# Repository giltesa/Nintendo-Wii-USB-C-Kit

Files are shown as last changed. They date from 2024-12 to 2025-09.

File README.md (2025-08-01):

# Nintendo Wii / Wii Mini / Wii U: USB-C Kit

The **Nintendo Wii: USB-C Kit** is a board that allows to replace the original power connector for a modern and standard USB-C.

**If your original connector / power supply is too old or damaged** and you need a new one, or **if you would like to power up your Nintendo Wii with a standard USB-C PD charger**, such as the charger for your phone, or laptop, you can do so with this kit.

This board is compatible with these three models:

*   Nintendo Wii
*   Nintendo Wii Mini
*   Nintendo Wii U

## HOW DOES IT WORK?

The **USB-C Power Delivery technology** (**USB-C PD**) allows for communication between the device and the power supply(charger), enabling the negotiation of the voltage to be supplied through the USB-C cable. In this case, the microchip included on this board is configured to request 12v or 15v(1), signaling to the charger that it requires 12v or 15v(1) to run on. If the charger is compatible, it will supply the requested voltage. If it’s not compatible, nothing will happen, and the Nintendo Wii won’t power on.

 **(1)** The circuit has a selection jumper; if you solder it in one position, the circuit will require 12v, and if you solder it in the other position, it will require 15v from the power supply.

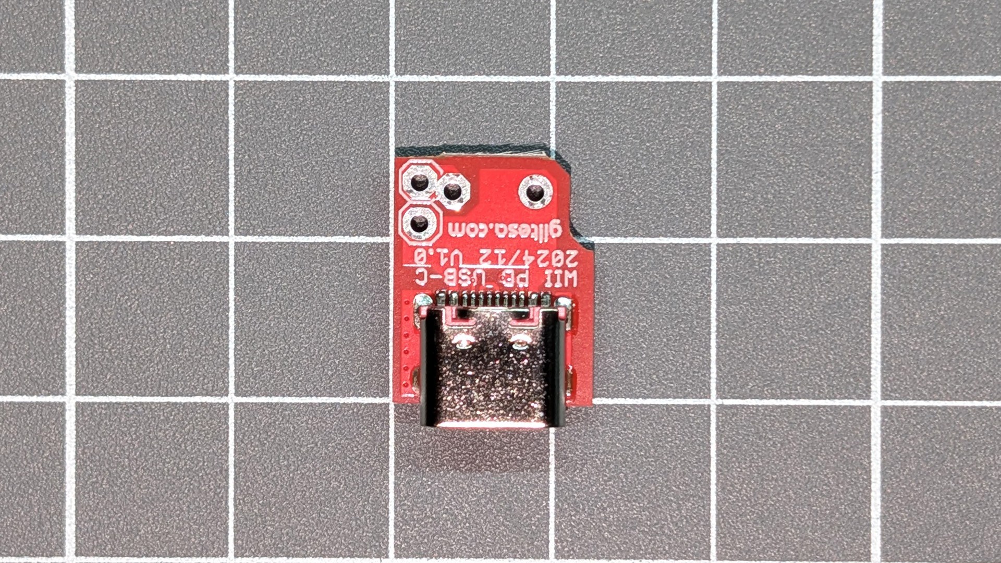
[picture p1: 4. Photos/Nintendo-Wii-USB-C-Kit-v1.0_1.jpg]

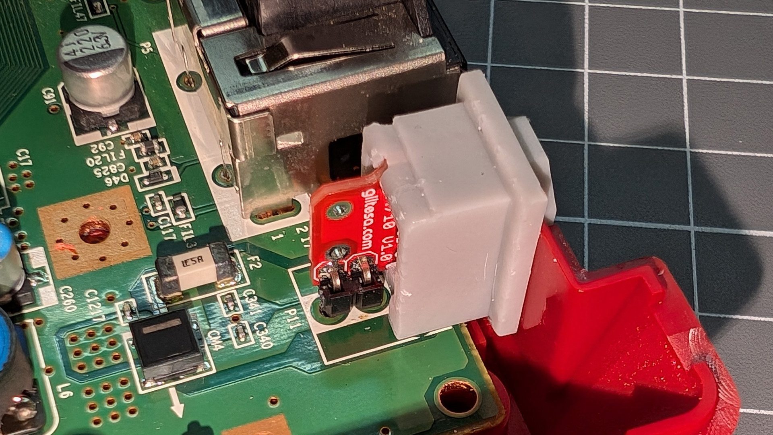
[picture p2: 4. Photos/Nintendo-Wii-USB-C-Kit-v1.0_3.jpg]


## Would you like it?

[**Nintendo Wii: USB-C Kit**](https://shop.giltesa.com/?p=2794)

## License

This project is licensed under a **Creative Commons** license:
**[Attribution-NonCommercial-ShareAlike 4.0 International (CC BY-NC-SA 4.0) ](https://creativecommons.org/licenses/by-nc-sa/4.0/)**

Check the [LICENSE.md](LICENSE.md) for more information.

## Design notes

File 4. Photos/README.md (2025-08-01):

WII
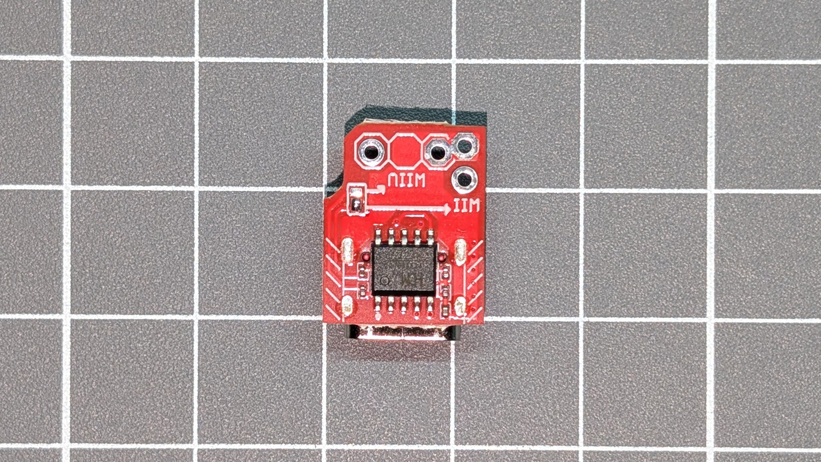
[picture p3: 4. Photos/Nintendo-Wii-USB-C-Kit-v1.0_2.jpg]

WII
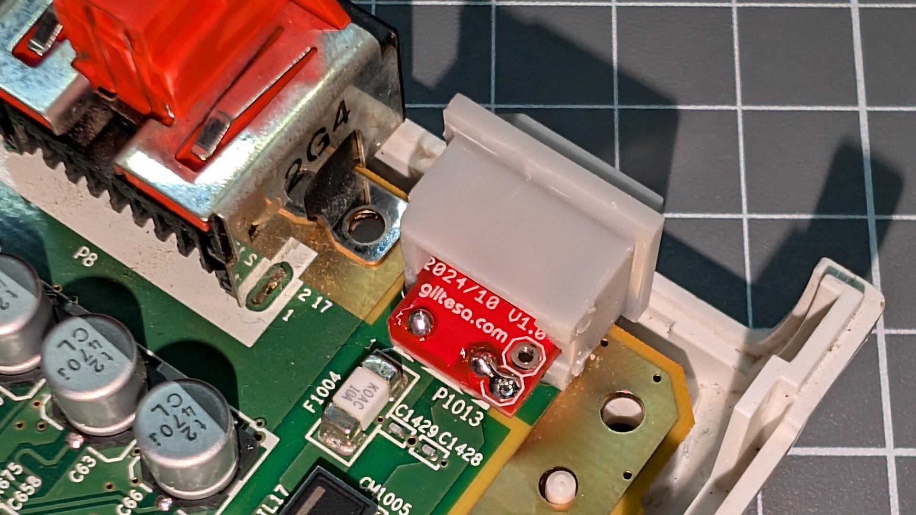
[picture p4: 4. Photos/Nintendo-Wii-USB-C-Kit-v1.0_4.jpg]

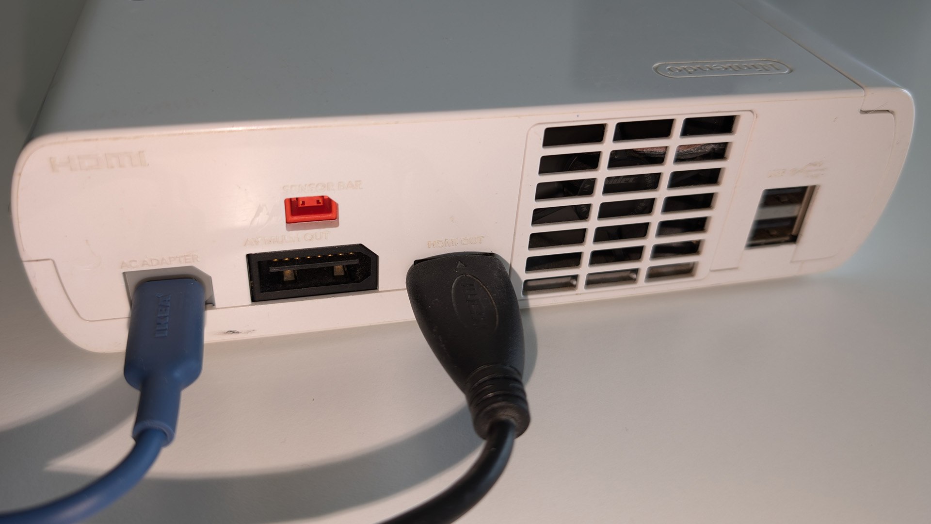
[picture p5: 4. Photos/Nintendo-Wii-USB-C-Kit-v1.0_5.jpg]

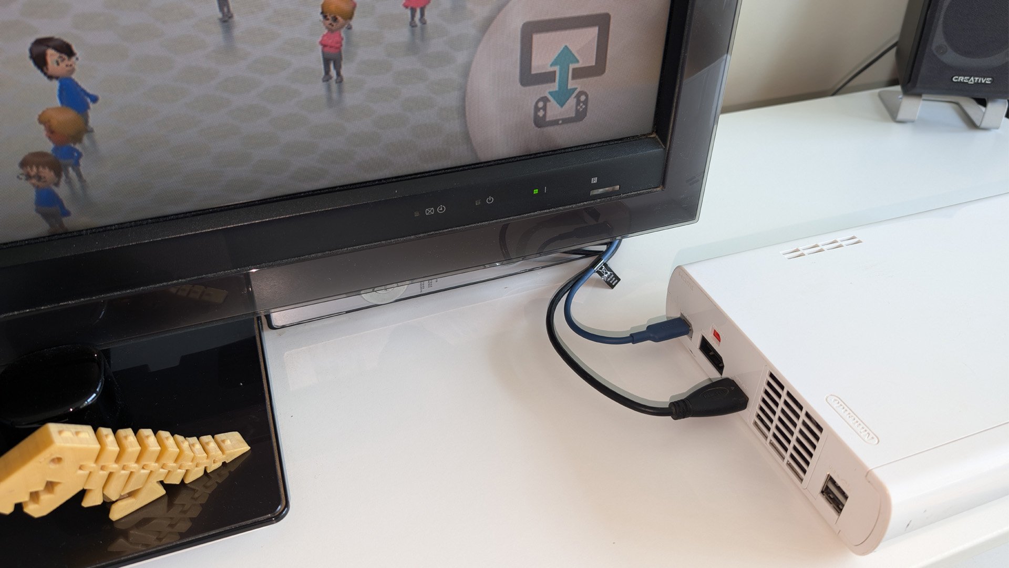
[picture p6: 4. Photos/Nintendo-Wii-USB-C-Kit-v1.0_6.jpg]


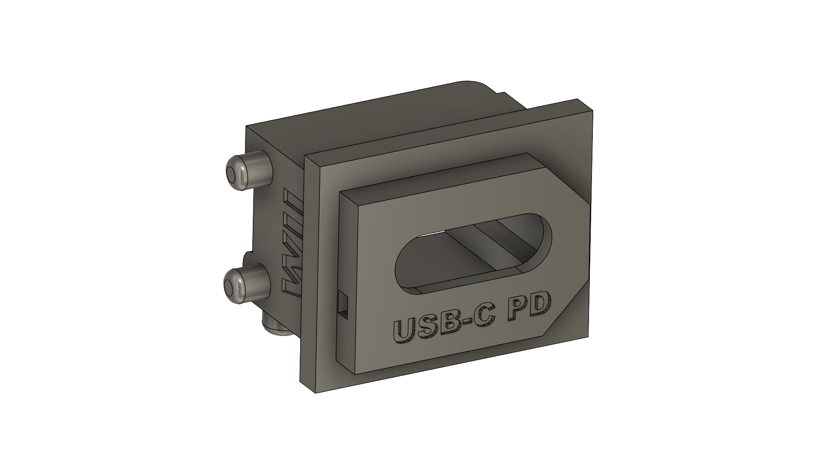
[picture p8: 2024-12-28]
2. Renders, 3D models/Cap/Wii & WiiU CAP v31.png

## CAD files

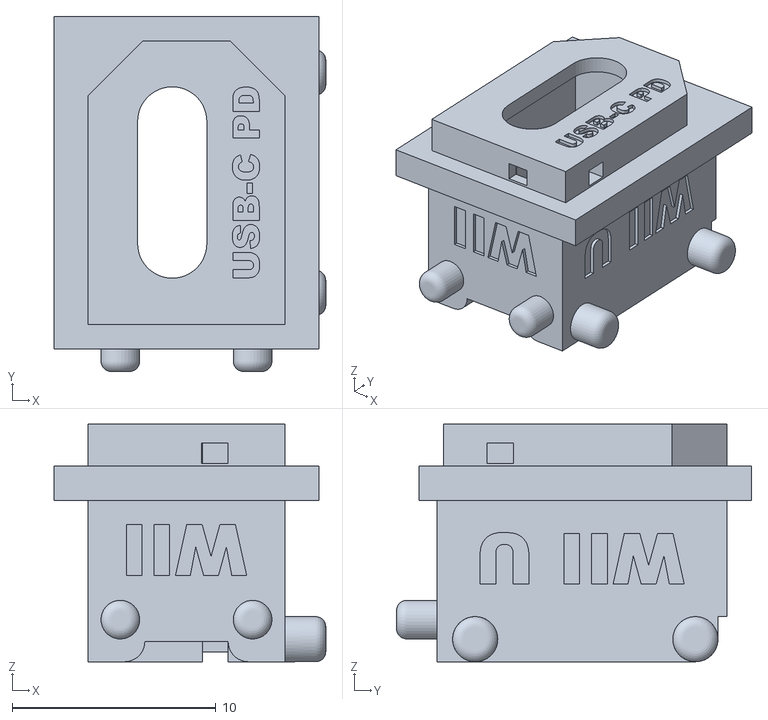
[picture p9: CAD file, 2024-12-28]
2. Renders, 3D models/Cap/Wii CAP v31.stl
13.3 x 17.4 x 11.7

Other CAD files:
2. Renders, 3D models/PCB Black.skp

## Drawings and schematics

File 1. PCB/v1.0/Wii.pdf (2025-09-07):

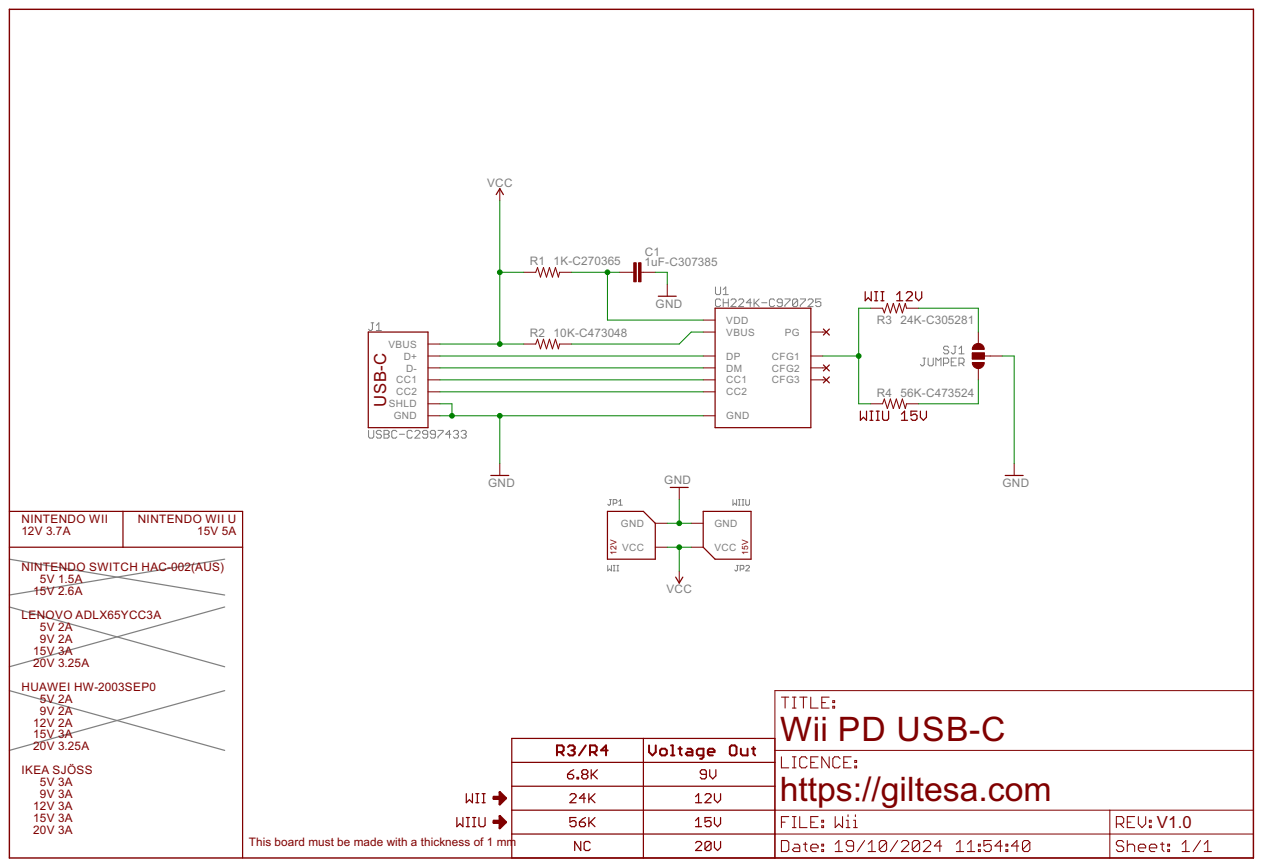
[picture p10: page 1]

This board must be made with a thickness of 1 mm

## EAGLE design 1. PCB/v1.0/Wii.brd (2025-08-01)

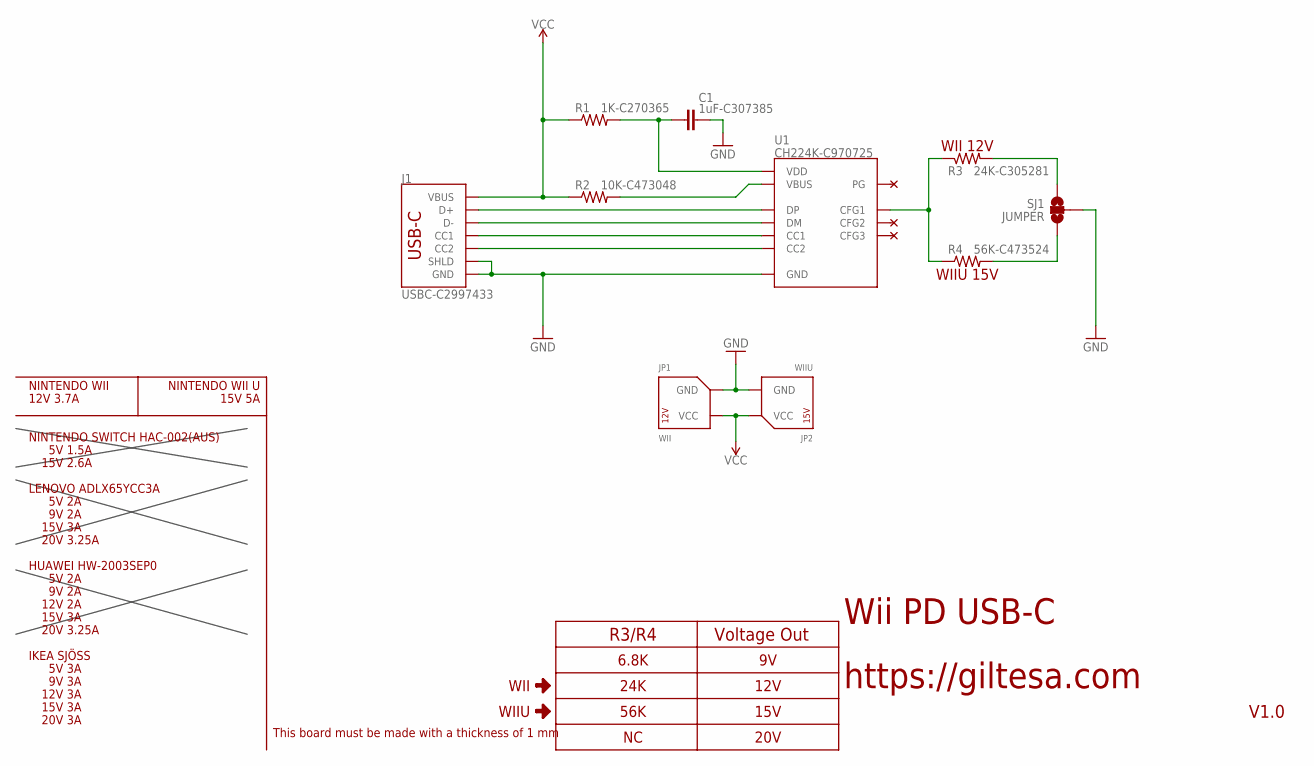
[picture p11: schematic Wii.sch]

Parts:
C1: 1uF-C307385; C0201
J1: USBC-C2997433; USB-C_16P
JP1: WII; WII_1X02
JP2: WIIU; WIIU_1X02
R1: 1K-C270365; R0201
R2: 10K-C473048; R0201
R3: 24K-C305281; R0201
R4: 56K-C473524; R0201
SJ1: JUMPER; JUMPER-SMD-3_NO_SILK
U1: CH224K-C970725; ESSOP10

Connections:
CC1: J1.A5-CC1 (CC1), U1.7 (CC1)
CC2: J1.B5-CC2 (CC2), U1.6 (CC2)
D+: J1.A6-DP1 (D+), J1.B6-DP2 (D+), U1.4 (DP)
D-: J1.A7-DN1 (D-), J1.B7-DN2 (D-), U1.5 (DM)
GND: C1.2, J1.GND1 (GND), J1.GND2 (GND), J1.SHLD1 (SHLD), J1.SHLD2 (SHLD), J1.SHLD3 (SHLD), J1.SHLD4 (SHLD), JP1.GND1 (GND), JP2.GND1 (GND), SJ1.2, U1.0 (GND)
unnamed: R3.2, SJ1.1
unnamed: R3.1, R4.1, U1.9 (CFG1)
unnamed: R4.2, SJ1.3
unnamed: R2.2, U1.8 (VBUS)
VCC: J1.VBUS1 (VBUS), J1.VBUS2 (VBUS), JP1.VCC1 (VCC), JP2.VCC1 (VCC), R1.1, R2.1
VDD: C1.1, R1.2, U1.1 (VDD)

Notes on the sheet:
Wii PD USB-C
https://giltesa.com
V1.0
This board must be made with a thickness of 1 mm
NINTENDO SWITCH HAC-002(AUS)
5V 1.5A
15V 2.6A
HUAWEI HW-2003SEP0
5V 2A
9V 2A
12V 2A
15V 3A
20V 3.25A
NINTENDO WII
12V 3.7A
R3/R4
Voltage Out
6.8K
24K
56K
12V
15V
20V
LENOVO ADLX65YCC3A
IKEA SJÖSS
5V 3A
9V 3A
12V 3A
20V 3A
WII
WIIU
WII 12V
WIIU 15V
NINTENDO WII U
15V 5A

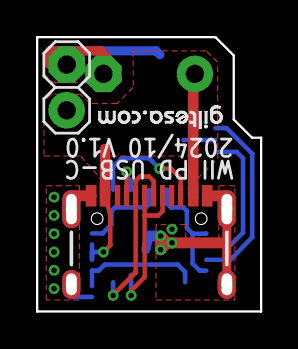
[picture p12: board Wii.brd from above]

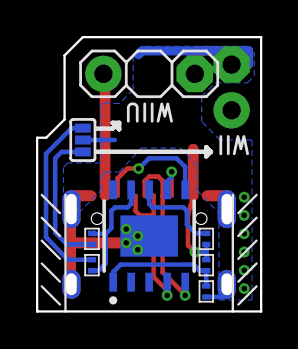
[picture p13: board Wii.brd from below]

Board: 2 copper layers, 12.4 x 15.2 mm, 11 parts (8 on the bottom side), 11 nets.

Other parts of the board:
U$28: GILTESA.COM_7MM_MASK

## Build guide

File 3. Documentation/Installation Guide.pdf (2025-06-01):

# USB-C KIT For

# Nintendo Wii Wii Mini Wii U

PRODUCT

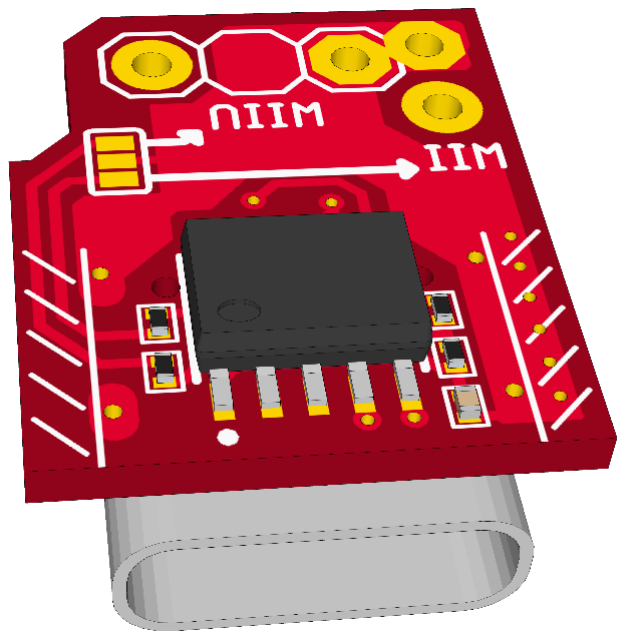
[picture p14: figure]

HTTPS://SHOP.GILTESA.COM/PRODUCT/NINTENDO-WII-USB-C-KIT

# PLEASE READ THROUGH THESE INSTRUCTIONS

ENTIRELY BEFORE ATTEMPTING TO INSTALL.

# WARNING: IF YOU ARE NOT COMFORTABLE WITH SOLDERING, OR PERFORMING ANY STEP IN THIS

GUIDE, DO NOT PERFORM THE INSTALL YOURSELF.

# FIND SOMEONE WHO IS COMFORTABLE TO DO IT FOR

YOU.

INDEX

# Description

The Nintendo Wii: USB-C Kit is a board that allows to replace the original power connector for a modern and standard USB-C.

If your original connector or power supply is too old or damaged and you need a new one, or if you would like to power your Nintendo Wii with a standard USB-C PD charger, such as the charger for your phone or laptop, you can do so with this kit.

This board is compatible with the following three models:

- Nintendo Wii
- Nintendo Wii Mini
- Nintendo Wii U

# HOW DOES IT WORK?

The USB-C Power Delivery technology (USB-C PD) allows for communication between the device and the power supply(charger), enabling the negotiation of the voltage to be supplied through the USB-C cable. In this case, the microchip included on this board is configured to request 12v or 15v

(1), signaling to the
charger that it requires 12v or 15v
(1) to run on. If the charger is compatible, it will supply the requested voltage. If it’s not compatible, nothing will happen, and the Nintendo Wii won’t power on.
(1) The circuit has a selection jumper; if you solder it in one position, the circuit will require 12v, and if you solder it in the other position, it will require 15v from the power supply.

# FEATURES

- Similar size to the original connector.
- External power through USB-C.

# INCLUDED

- 1 USB-C board.
- 1 right-angle 2-pin header for Wii and Wii Mini
- 1 straight-angle 2-pin header for Wii U.
- 1 Plastic cap for the USB-C board.

# Recommended / REQUIRED (NOT INCLUDED)

- Tri-wing and Phillips
screwdrivers.
- Tin soldering iron.
- Tin.
- Flux.
- Desoldering pump.
- Isopropyl alcohol.

# NOTES

The Nintendo Wii and Wii Mini run on 12V and 3.5A, while the Nintendo Wii U runs on 15V and 5A.

Make sure your power supply with Power Delivery (PD) can provide the necessary voltage for your console model. Also, ensure that the supplied current is equal to or as close as possible to the amount required by the console.

The console’s disc reader consumes a significant amount of current, around 1.9A. So, if you don’t plan to use it for loading games, this can reduce the power requirements and allow you to use a power supply with lower specifications.

All tests were conducted with the same power supply used for the GameCube kit, providing 12V or 15V and 3A:

- Ikea SJÖSS 45W 12V 3A, (https://www.ikea.com/es/en/p/sjoss-45w-2-port-usb-charger-fast-charging-80574438/) 13€

You will also need a USB-C to USB-C cable for PD. If you don’t have one, these will work:

- Ikea SITTBRUNN USB-C to USB-C 1m (https://www.ikea.com/es/en/p/sittbrunn-usb-c-to-usb-c-blue-30546650/)
- Ikea LILLHULT USB-C to USB-C 1.5 m (https://www.ikea.com/es/en/p/lillhult-usb-c-to-usb-c-dark-grey-50527603/)

# Board details

This small board comes almost fully assembled, except for the connector that will link it to the console. Since it is compatible with multiple models, you will need to select the appropriate connector for your console.

Similarly, the board includes an solder jumper that must be manually soldered to indicate the type of console you will be using. This sets the correct supply voltage.

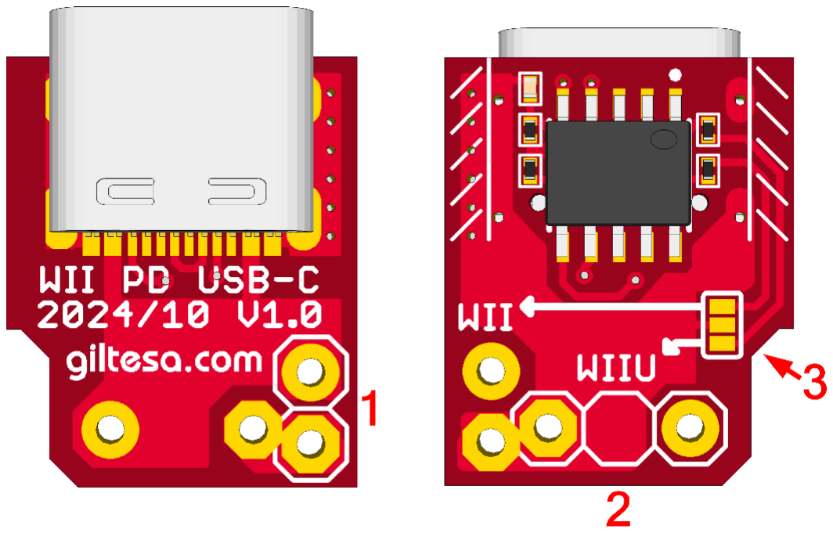
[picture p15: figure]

1. 2-pin 90º angled connector for Wii and Wii Mini.
2. 2-pin connector for Wii U.
3. Solder jumper, by default, configured for Wii and Wii Mini (12V).

# INSTALLATION STEPS

Please, carefully read the following steps for a successful installation.

## Pre installation Steps

Before the installation, your Wii may need some extra steps to have it ready for the kit.

1. Disassembly the CONSOLE

The disassembly steps for the Wii, Wii Mini, and Wii U vary greatly depending on each model.

Follow the iFixit disassembly guide for your specific model:

- Wii (https://www.ifixit.com/Guide/Nintendo+Wii+Motherboard+Replacement/3460)
- Wii Mini (https://www.ifixit.com/Guide/Nintendo+Wii+mini+Motherboard+Replacement/37774)
- Wii U (https://www.ifixit.com/Guide/Nintendo+Wii+U+Motherboard+Replacement/62492)

It is necessary to completely disassemble the console to access the power connector. Therefore, it is recommended to group and even label the different parts you are removing from the console. This way, to reassemble it, you only need to follow the reverse steps.

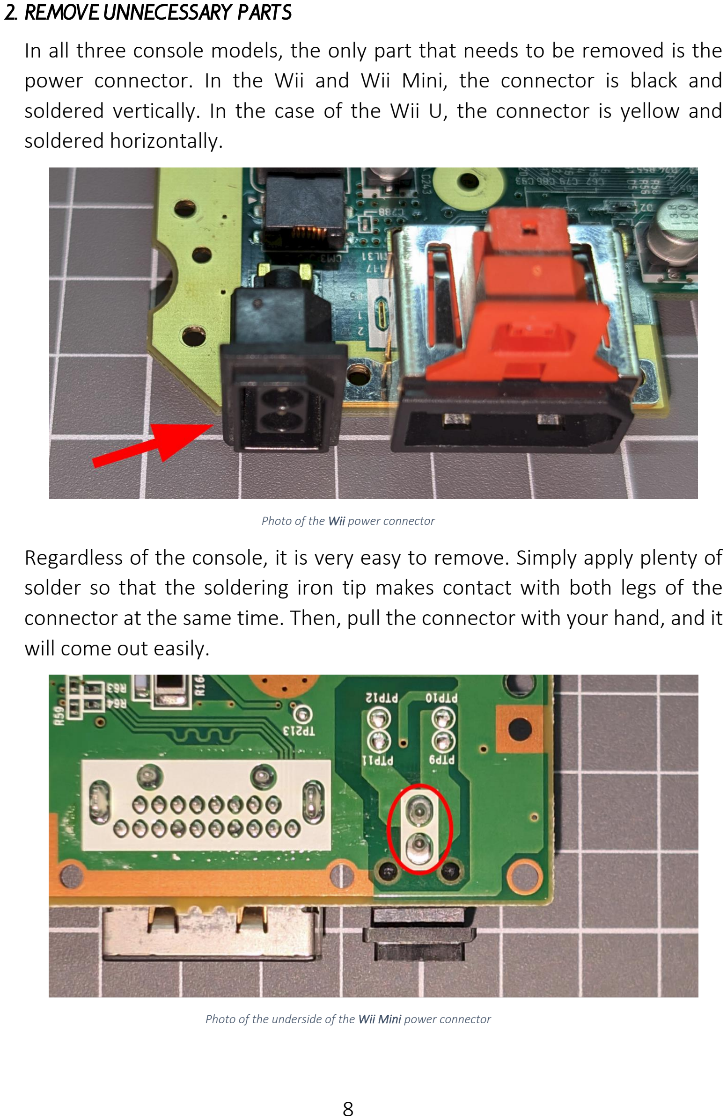
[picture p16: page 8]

2. Remove unnecessary parts

In all three console models, the only part that needs to be removed is the power connector. In the Wii and Wii Mini, the connector is black and soldered vertically. In the case of the Wii U, the connector is yellow and soldered horizontally.

Photo of the Wii power connector
Regardless of the console, it is very easy to remove. Simply apply plenty of solder so that the soldering iron tip makes contact with both legs of the connector at the same time. Then, pull the connector with your hand, and it will come out easily.

Photo of the underside of the Wii Mini power connector

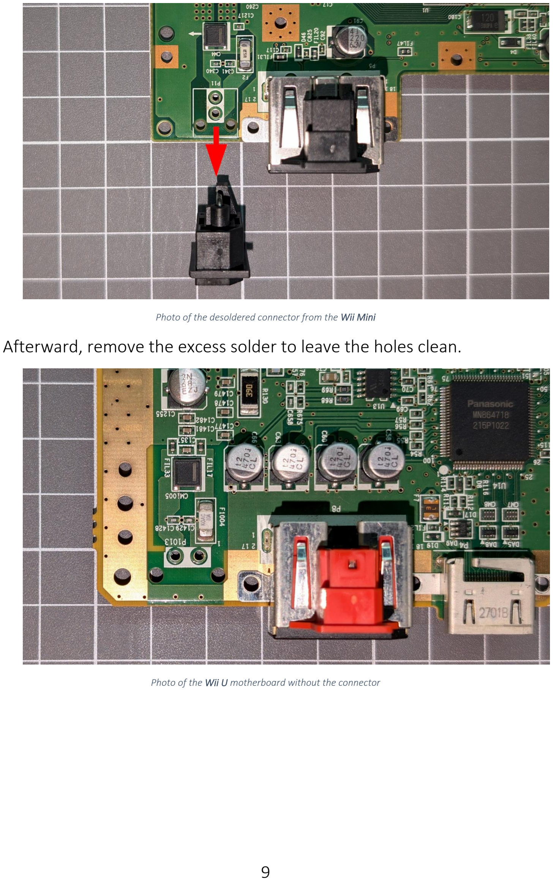
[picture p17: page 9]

Photo of the desoldered connector from the Wii Mini
Afterward, remove the excess solder to leave the holes clean.

Photo of the Wii U motherboard without the connector

## installation Steps

1. Board assembly

Now it's time to finish assembling the USB-C board.

Solder the soler jumper depending on your console model
On the underside of the board, where the chip is also located, you will see a solder jumper.

Depending on whether your console is a Wii / Wii Mini or a Wii U, you will need to solder this jumper in one position or another.

By default, this jumper is already soldered/configured for the Wii and Wii Mini, so if your console is one of these two, you can proceed to the next step.

### Wii & Wii Mini

Make sure to join the center and top pads of the solderjumper for your Wii & Wii Mini console.

### Wii U

Join the center and bottom pads of the solder jumper for your Wii U console.

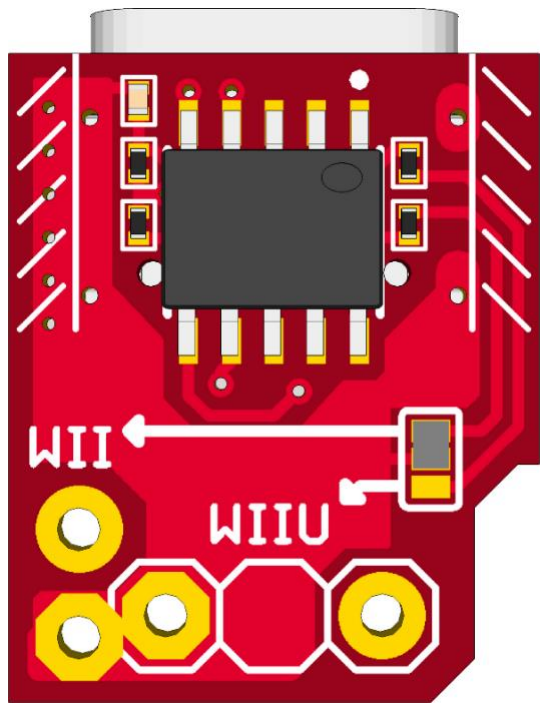
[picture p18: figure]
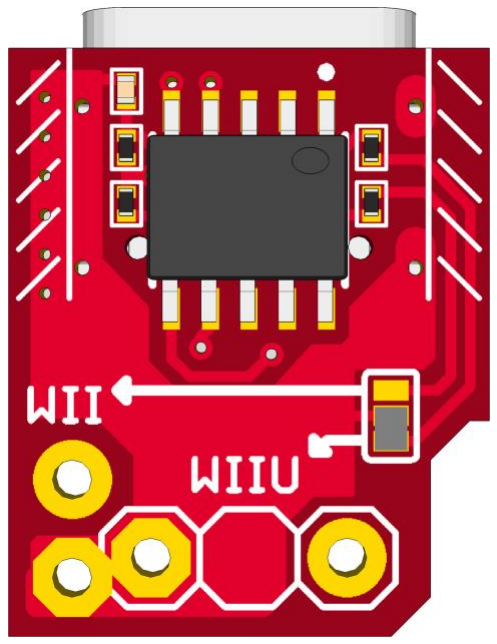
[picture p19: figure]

NOTE: It is very important that the jumper is soldered in the correct position; otherwise, the board could supply the wrong voltage and damage the console.

### Wii & Wii Mini

### Wii U

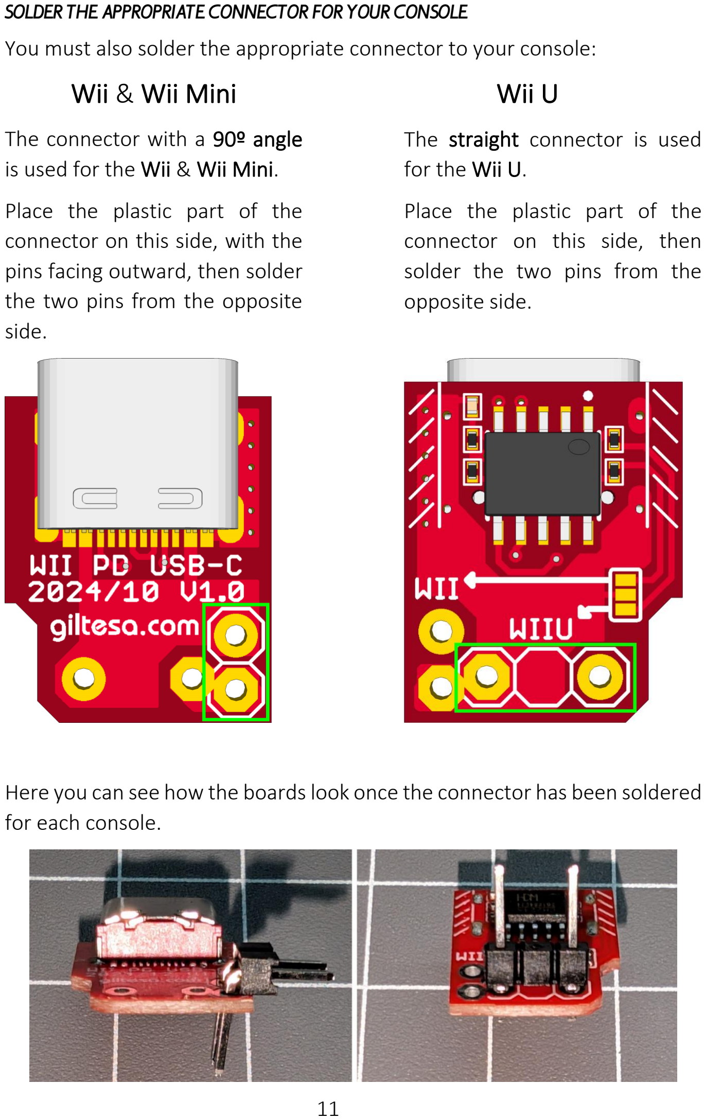
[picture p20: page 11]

Solder the appropriate connector for your console
You must also solder the appropriate connector to your console:

The connector with a 90º angle
is used for the Wii & Wii Mini.

Place the plastic part of the connector on this side, with the pins facing outward, then solder the two pins from the opposite side.

The straight connector is used for the Wii U.

Place the plastic part of the connector on this side, then solder the two pins from the opposite side.

Here you can see how the boards look once the connector has been soldered for each console.

Adjust the plastic cap for your console
Finally, it is necessary to cut the legs on the plastic cap that you won't need.

### Wii & Wii Mini

The plastic will be installed vertically, which means the horizontal legs labeled "Wii U" should be cut.

### Wii U

The plastic will be installed horizontally, which means the vertical legs labeled "Wii" should be cut.

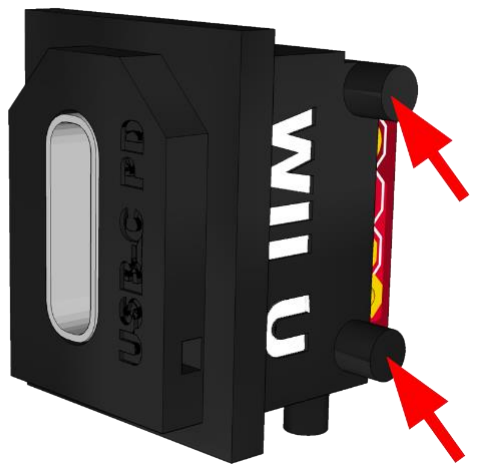
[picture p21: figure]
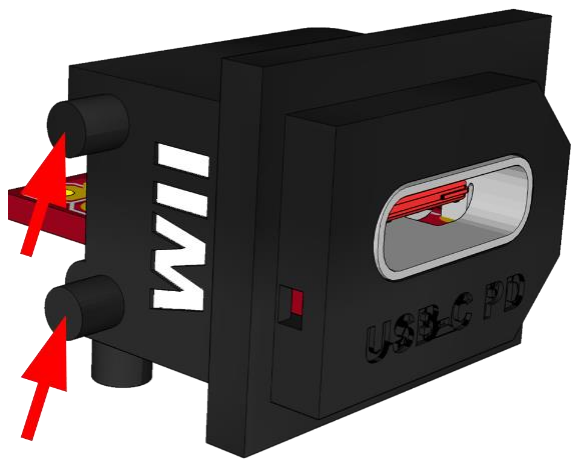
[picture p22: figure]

The plastic is strong but not very pressure-resistant. Try cutting the legs with a utility knife by making several passes as if using a knife. If you have a mini hand saw, use it for even better results.

Here you can see how the connector and plastic cap would look fully assembled and ready for installation.

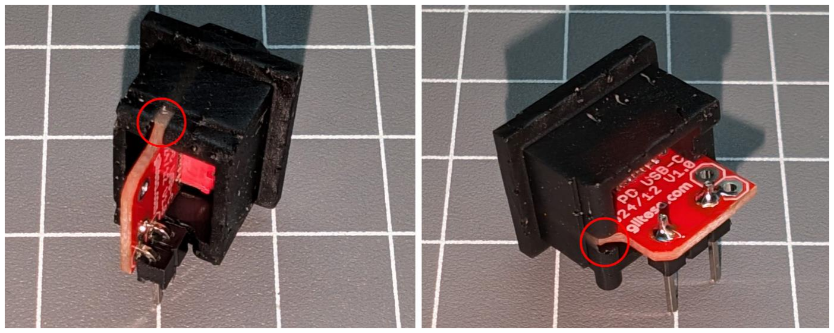
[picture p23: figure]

NOTE: It’s recommended to add a drop of instant glue in the area marked with a circle to join both parts.

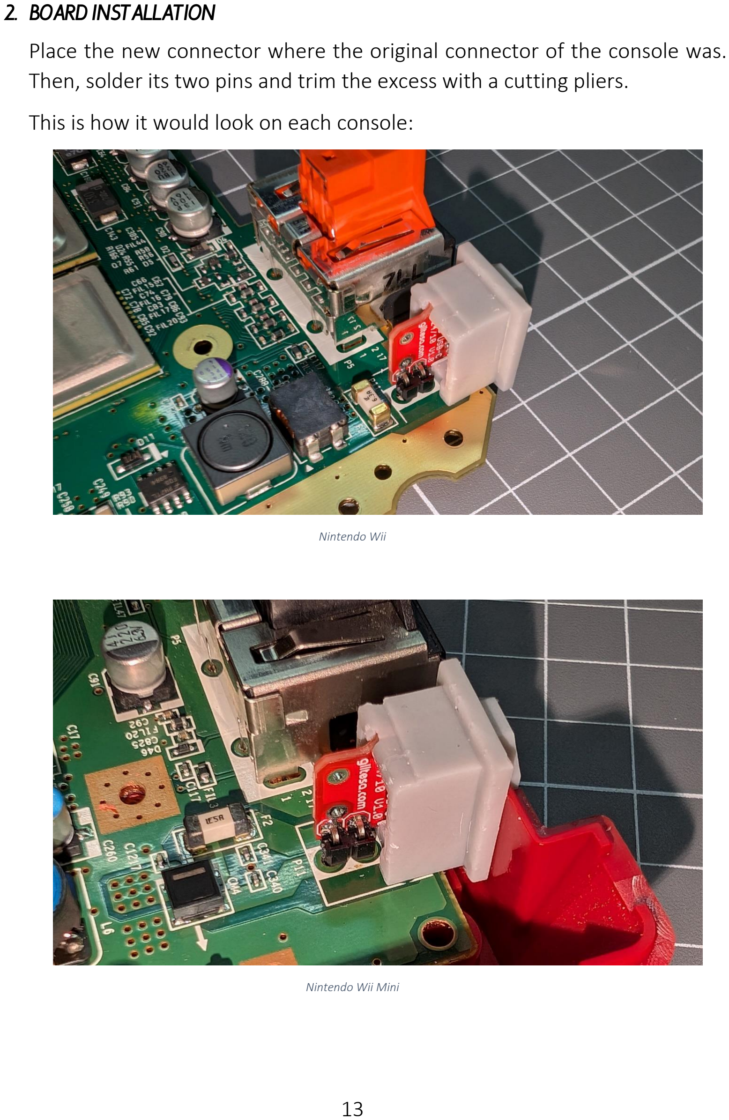
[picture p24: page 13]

2. board installation

Place the new connector where the original connector of the console was. Then, solder its two pins and trim the excess with a cutting pliers.

This is how it would look on each console:

Nintendo Wii

Nintendo Wii Mini

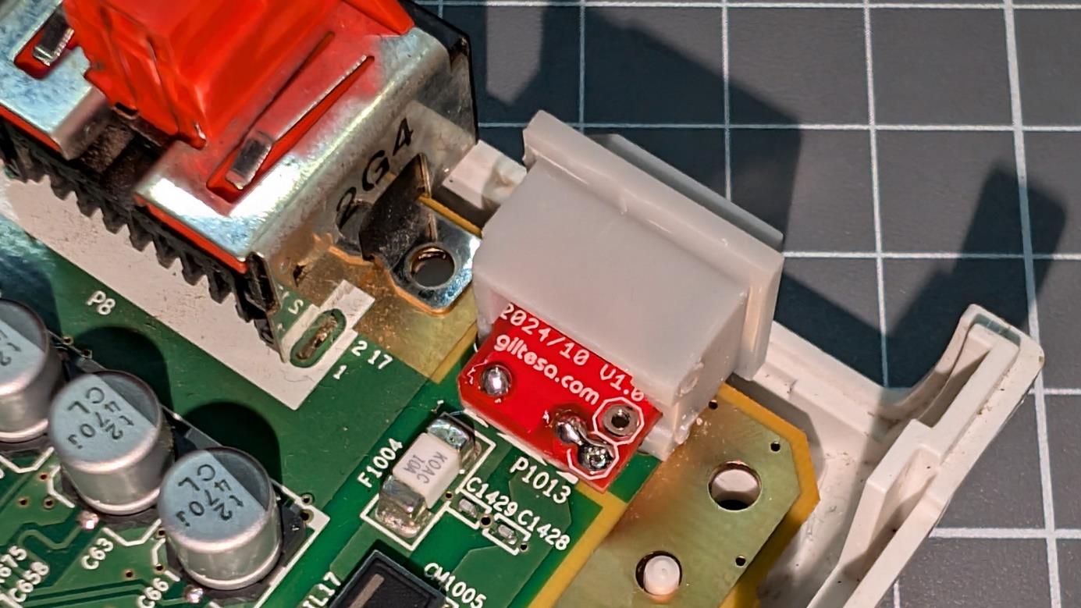
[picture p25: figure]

Nintendo Wii U

After this, you can fully reassemble the console; the installation is complete.

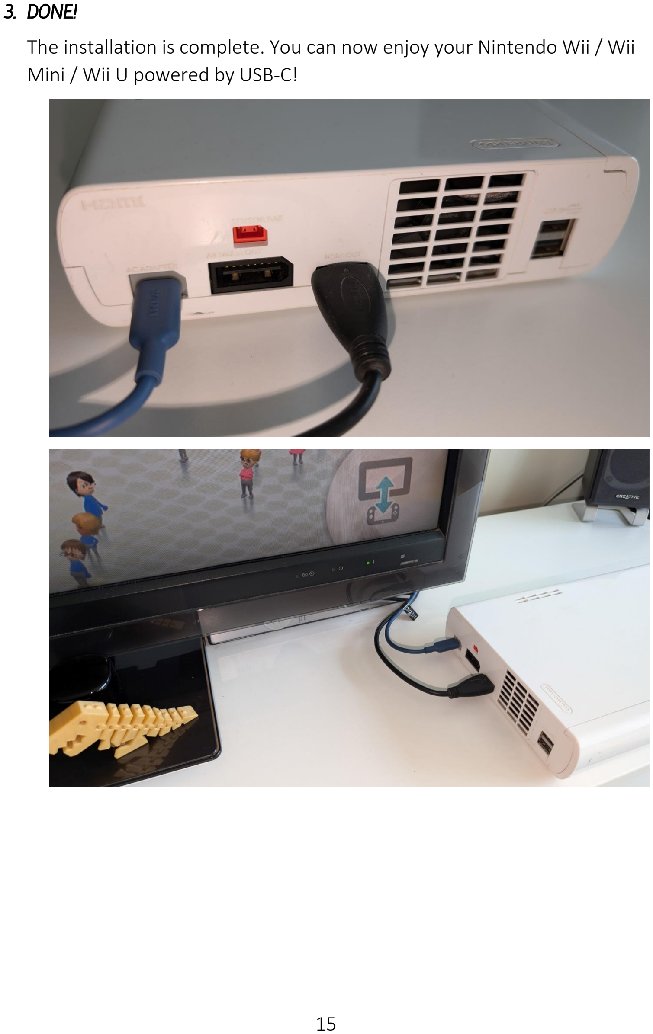
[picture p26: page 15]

3. Done!

The installation is complete. You can now enjoy your Nintendo Wii / Wii Mini / Wii U powered by USB-C!

# Frequently Asked Questions - FAQ

1. The WII doesn't turn on.
Make sure you are using a USB-C power supply that can provide an output voltage of 12V (for Wii / Wii Mini) or 15V (for Wii U) and an electric current of at least 3A.

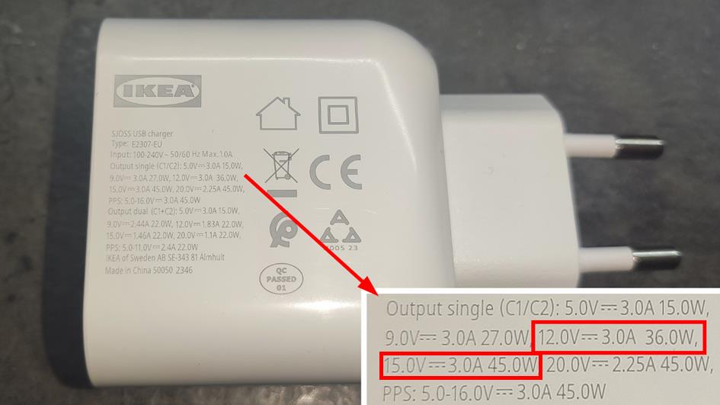
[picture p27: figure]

2. Can this kit be used with other mods?
Of course, as long as you use the appropriate power supply, then you can use any other mod or accessory you would normally use with the original power supply.

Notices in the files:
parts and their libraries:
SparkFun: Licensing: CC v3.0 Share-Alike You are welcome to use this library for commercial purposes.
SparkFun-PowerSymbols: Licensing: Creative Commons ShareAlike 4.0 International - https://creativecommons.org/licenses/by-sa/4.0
